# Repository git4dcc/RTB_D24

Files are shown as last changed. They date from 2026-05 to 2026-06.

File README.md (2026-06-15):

# RTB_D24




My Homebrew D24 is a single-sided DIY mobile decoder featuring a NEM-651 connector. While it shares the exact same dimensions as the [D16](https://github.com/git4dcc/RTB_D16), it offers additional AUX channels and supports WS28xx LED connections. It is fully designed for integration into the RTB digital control ecosystem.

<details>
<summary>See also</summary>

- [RTB_D16 - NEM651](/../../../../git4dcc/RTB_D16)
- [RTB_D20 - NEM651](/../../../../git4dcc/RTB_D20)
- [RTB_D21 - Next18](/../../../../git4dcc/RTB_D21)
- [RTB_D22 - Plux16](/../../../../git4dcc/RTB_D22)
- [RTB_D23 - NEM652](/../../../../git4dcc/RTB_D23)

</details>

<details>
<summary>User Guides</summary>

- User Guide - DE
- [User Guide - EN](https://rtb4dcc.de/rtb_decoder_reference_en/)

</details>

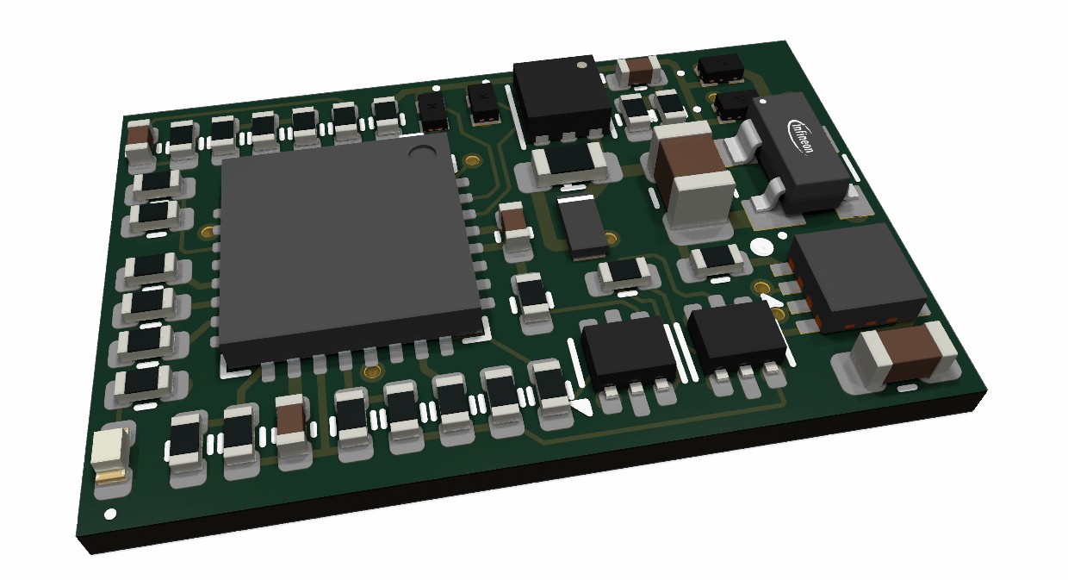
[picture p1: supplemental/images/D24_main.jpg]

<br>

The decoder has the following features,
- **NEM-651** connector
- **DCC**
  - DCC-A automatic logon
  - DCC-R protocol extension
  - Service Mode Programming
- **Railcom**
  - Channel 1/2
  - POM, xPOM
  - DYN: Speed, QoS, Track-voltage, Motor-current, AUX-current, Temp, Distance travelled
- Single sided
- Dimension: 17 x 11 mm
- 7-20V track voltage
- heartbeat LED
- adjustable max motor current (default 300mA)
- adjustable max AUX current (default 500mA)
- over temp protection
- Function output: LV/LR/AUX1/AUX2 (dimmable, 1.4kHz) open drain
- Function output: AUX3/AUX4/AUX5/AUX6/AUX7 logic level (5V)
  - AUX3/AUX4 can be configured to drive WS28xx chips
- optional external buffer capacitor (max. 1500uF)
- <10mA idle power consumption
- Firmware update over main tracks via DCC-R protocol

# Hardware
The current PCB layout uses SMD footprints with 0.5mm pitch and mainly 0402 parts. Reflow soldering is recommended, handsoldering will be difficult.

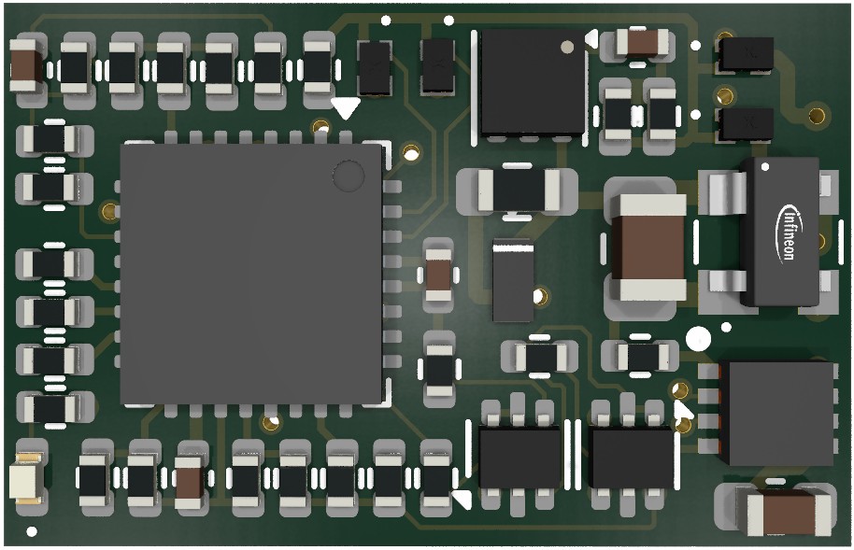
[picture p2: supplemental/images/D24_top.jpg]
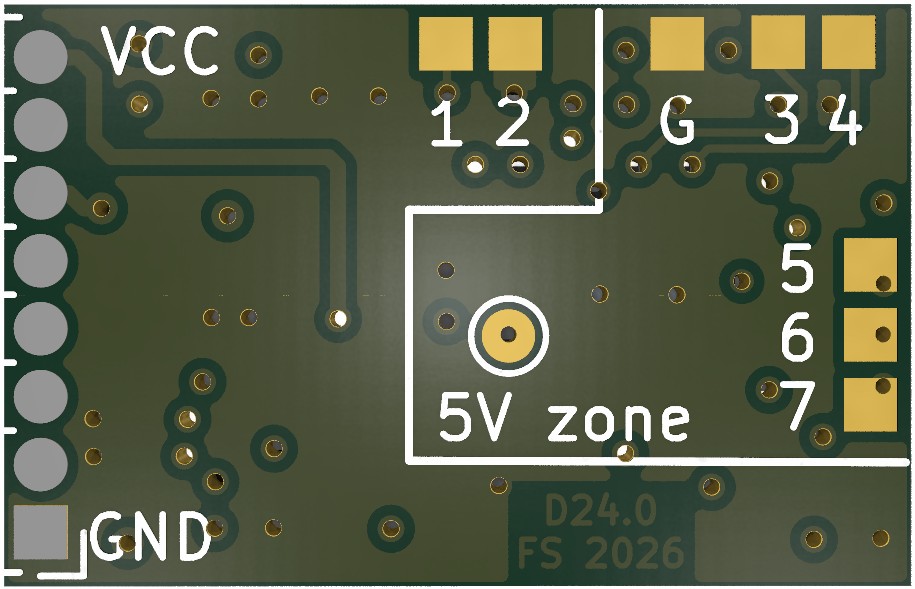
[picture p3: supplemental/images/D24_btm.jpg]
   

**Note:** The '5V zone' silk text can be misleading as the above test point is **not** 5V source but rather the UPDI interface.

## PCB
- 6-layer PCB, FR4, 17 x 11 x 0.8mm (single sided)
- CPU: AVR64DA32
- Motor bridge: DRV8231
- Connector: NEM-651

## Kicad
[Schematic](doc/D24_schematic.pdf) | [Layout](doc/D24_layout.pdf) | [Gerber](gerber)

<details>
<summary>Dependency</summary>
<br>

:yellow_circle: Requires my Kicad project library [RTB_SamacSys](https://github.com/git4dcc/RTB_SamacSys) in the same directory tree.

</details>

## Firmware
Filename structure: { **pcb** }{ **code** }{ **version** }.hex

Example: **D16F0001**.hex

| | Description |
| --- | --- |
| **pcb** | Name of matching hardware (**D24**) |
| **code** | Type of code contained (**R**=rom, **B**=bootloader, **F**=flash, **U**=bld update, **P**=UPDI factory code) |
| **version** | Release version (**####**) |

[Firmware files](firmware)

# Images
| top | bottom |
| --- | --- |
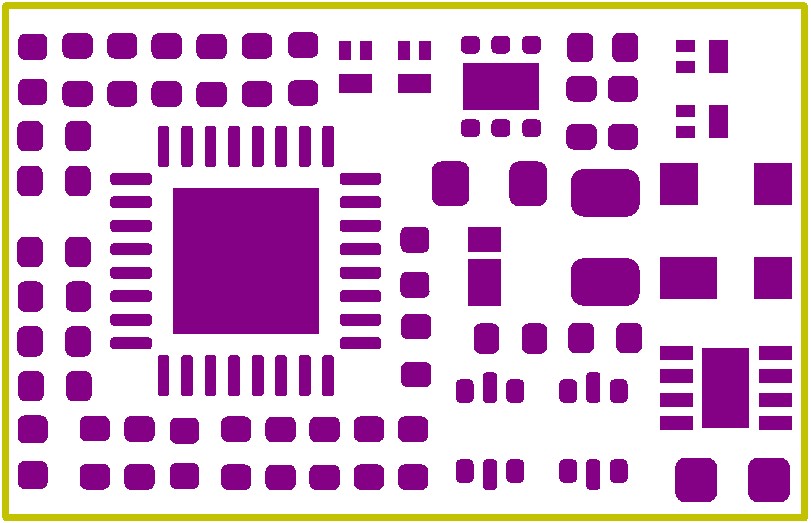
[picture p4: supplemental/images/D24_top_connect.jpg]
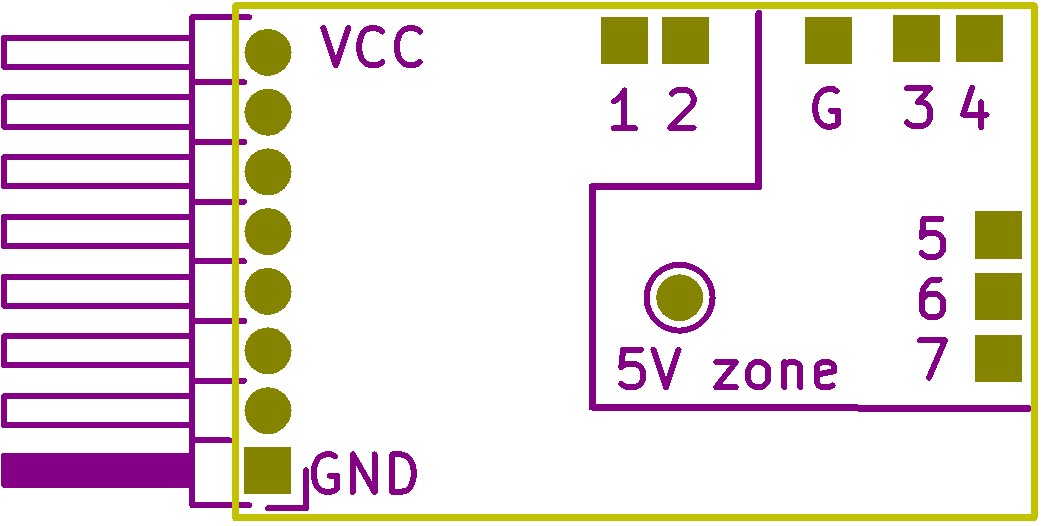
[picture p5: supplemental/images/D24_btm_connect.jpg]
|  |  |

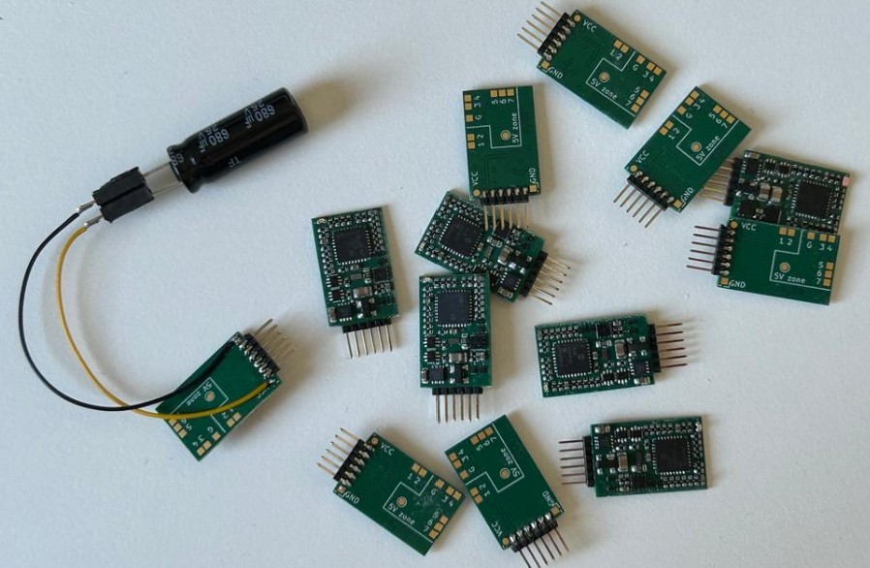
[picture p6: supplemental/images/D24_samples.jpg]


# YouTube
Some YouTubes to see the D24 decoder in action.<br><br>

This project is intended for hobby use only and is distributed in accordance with the Apache License 2.0 agreement.

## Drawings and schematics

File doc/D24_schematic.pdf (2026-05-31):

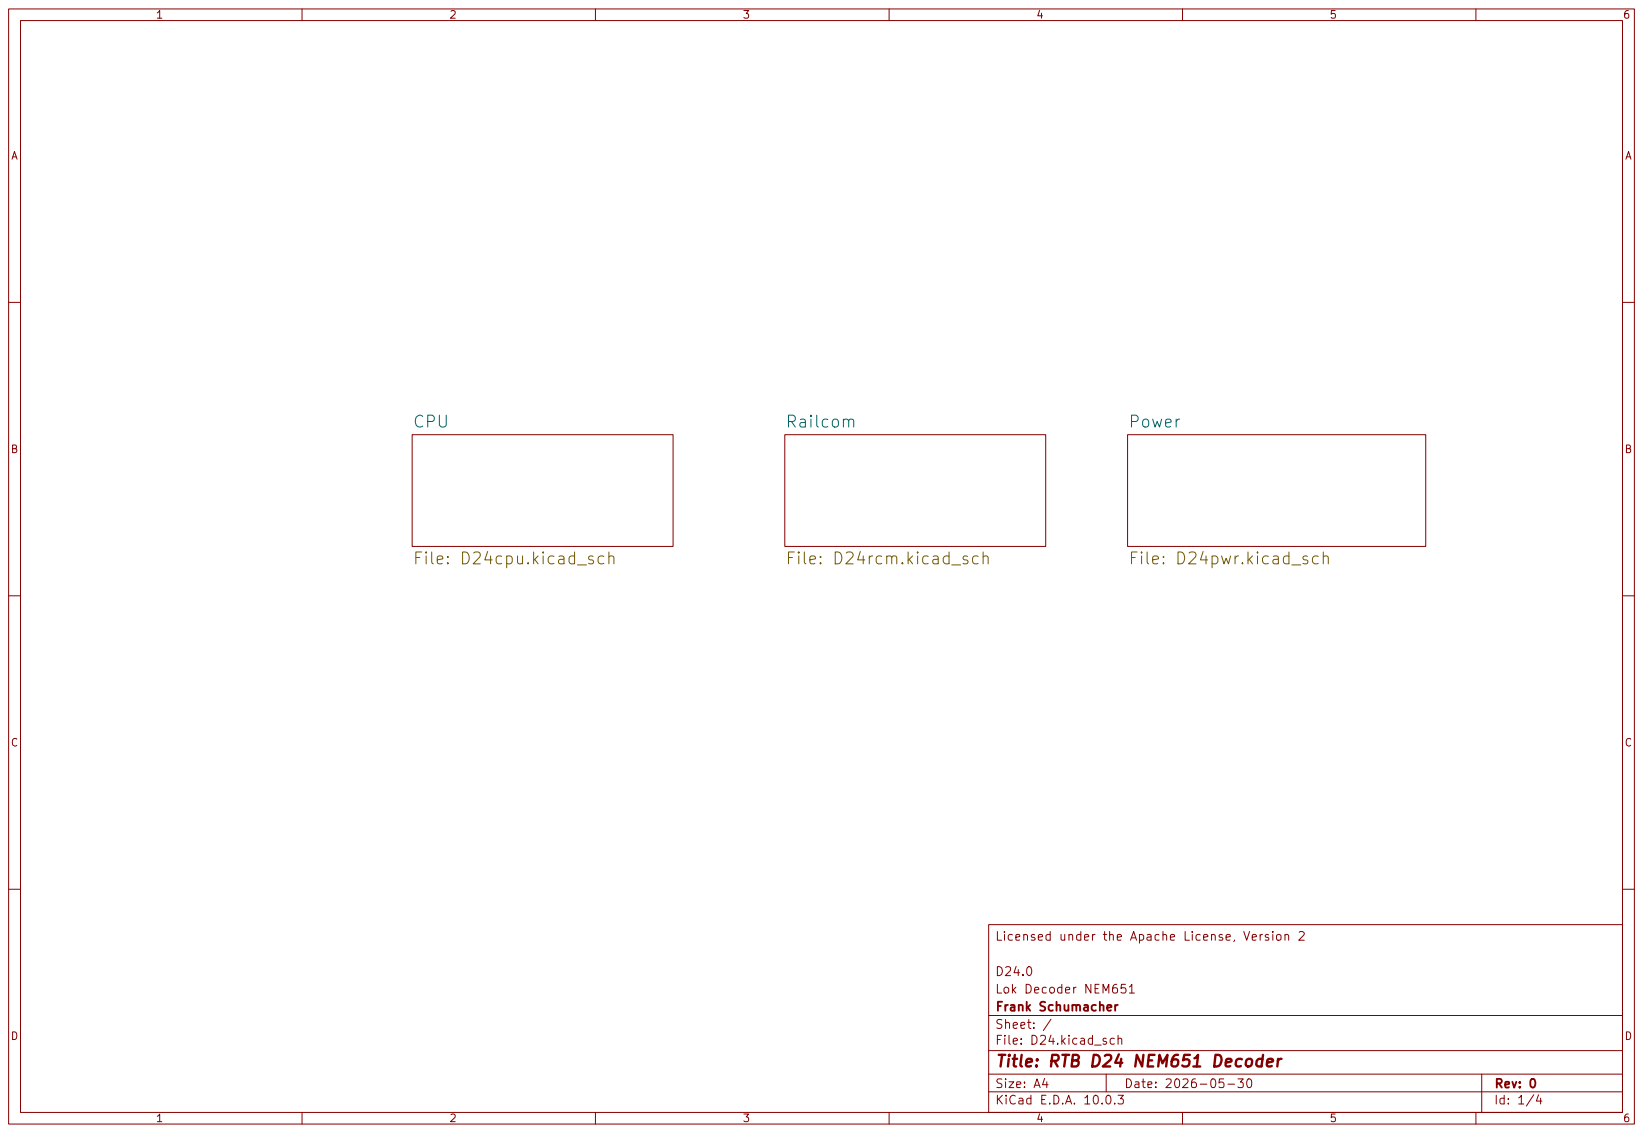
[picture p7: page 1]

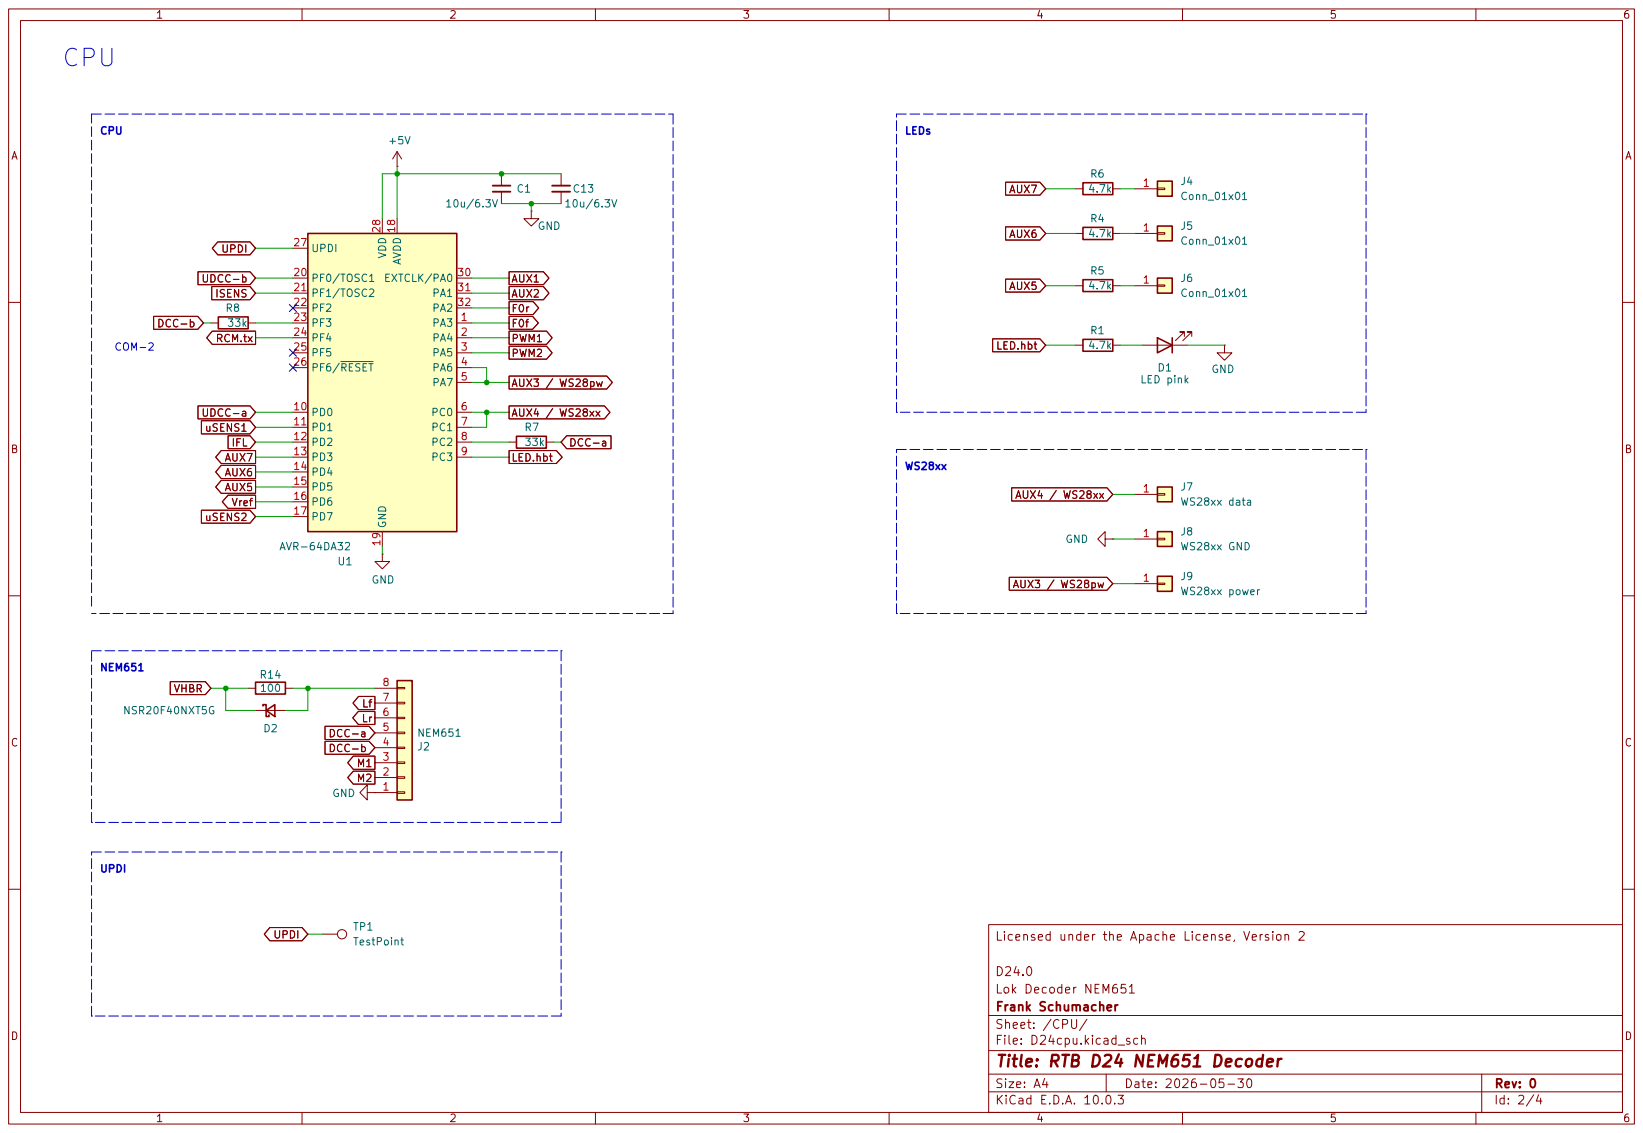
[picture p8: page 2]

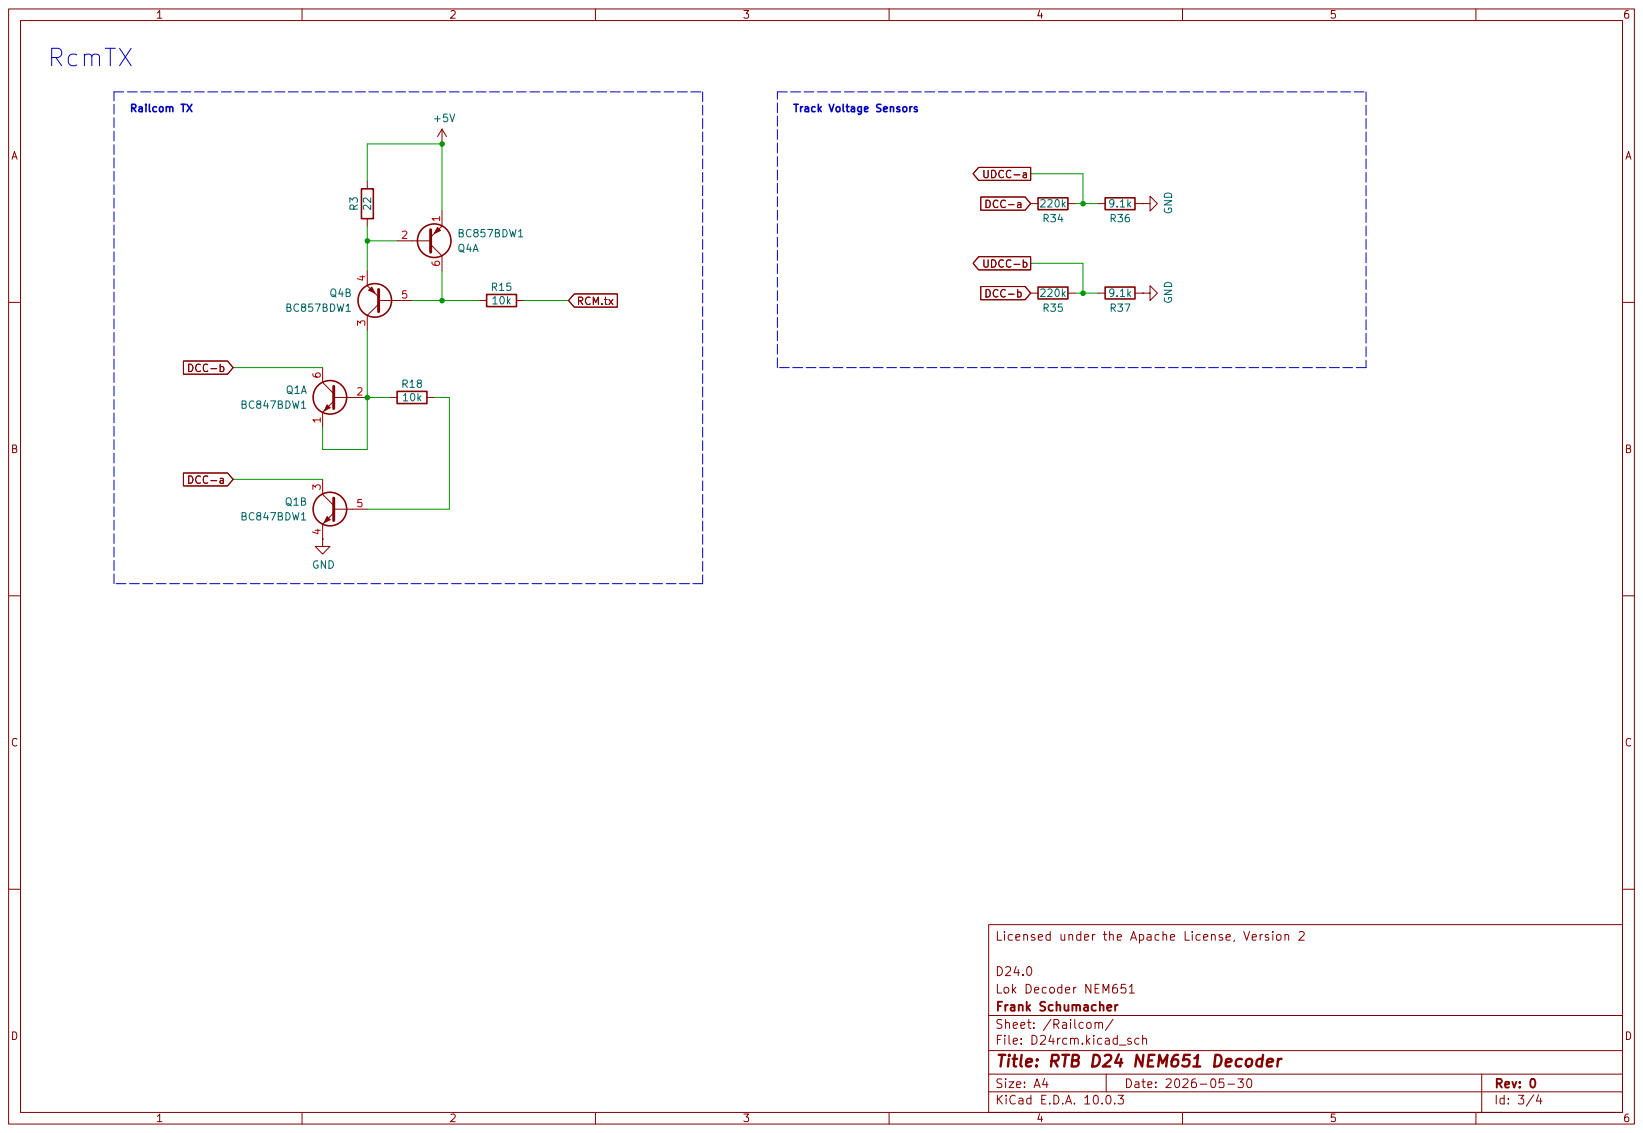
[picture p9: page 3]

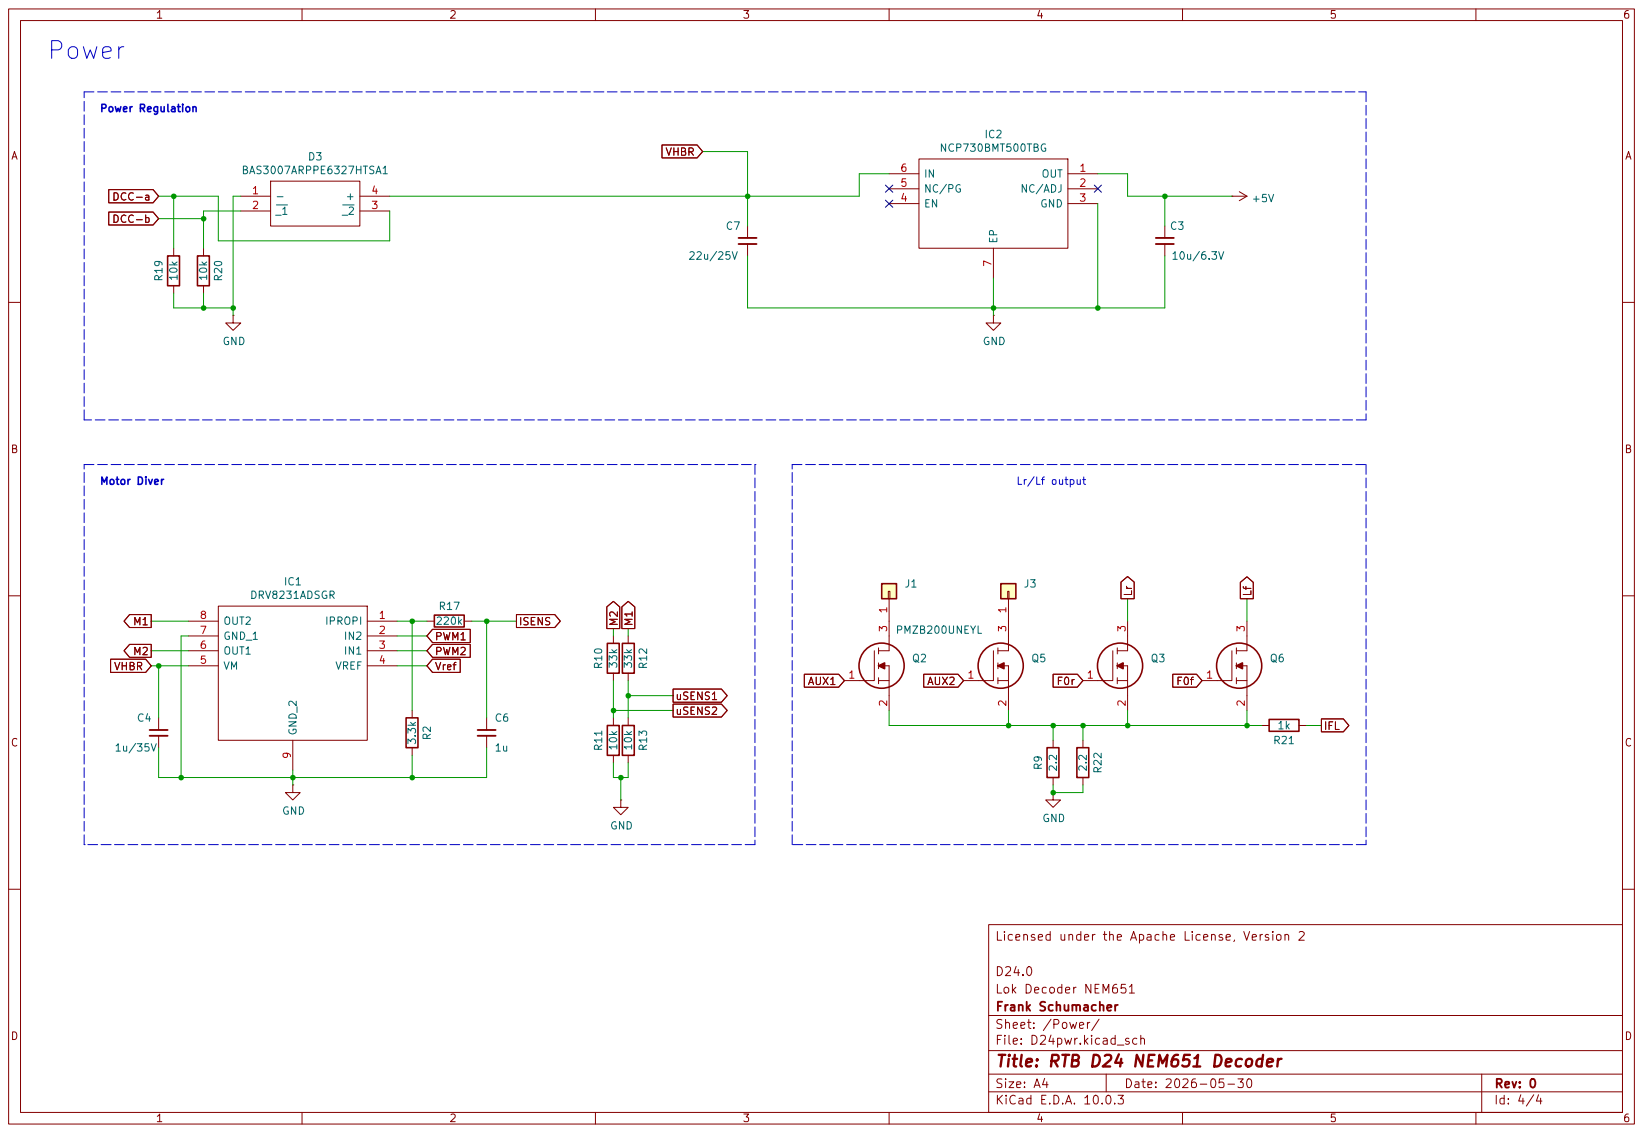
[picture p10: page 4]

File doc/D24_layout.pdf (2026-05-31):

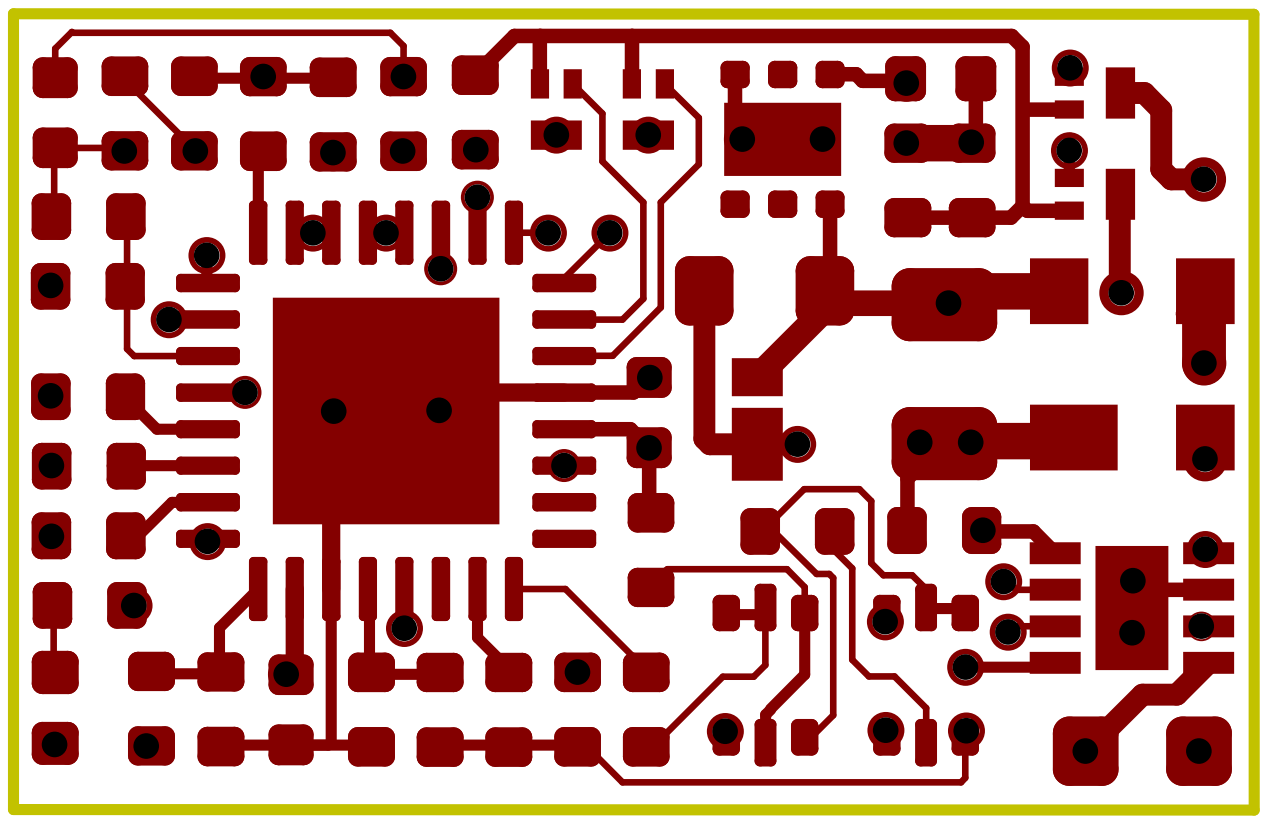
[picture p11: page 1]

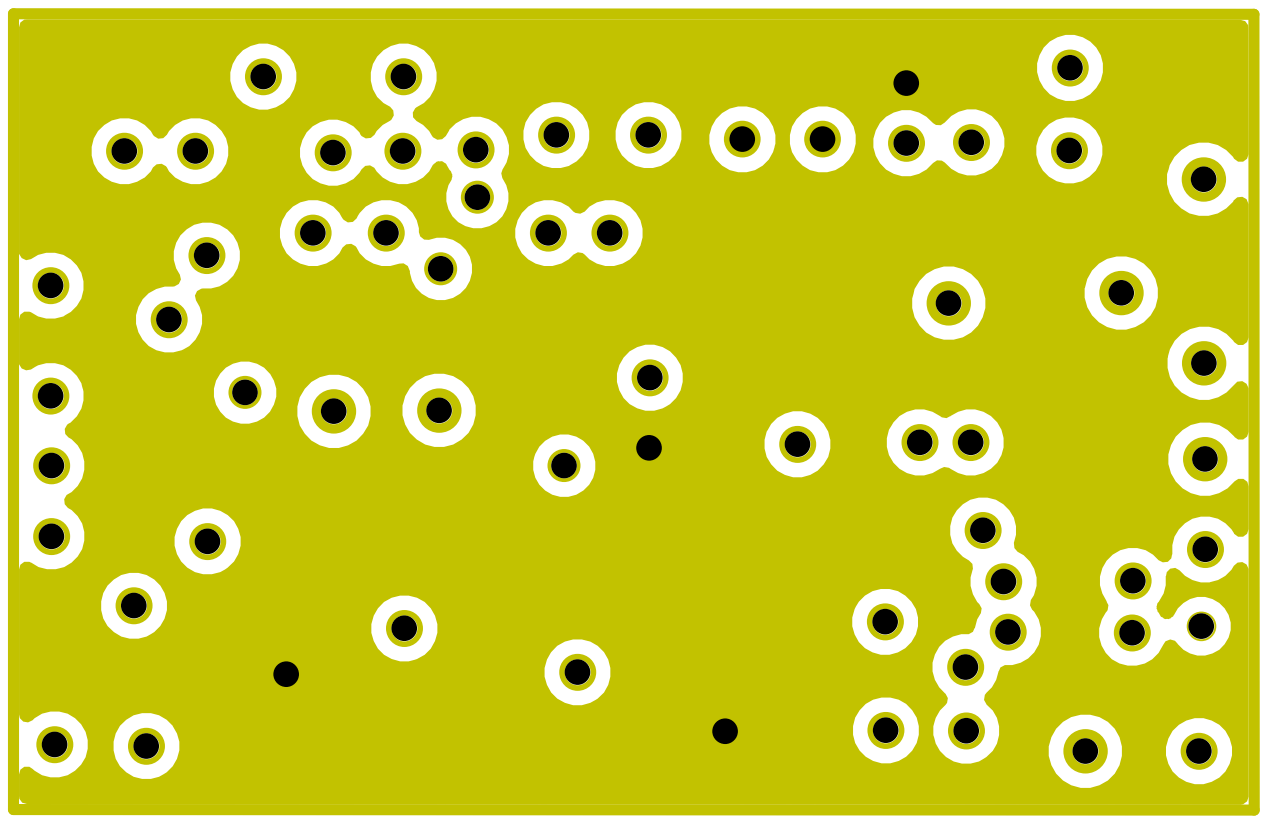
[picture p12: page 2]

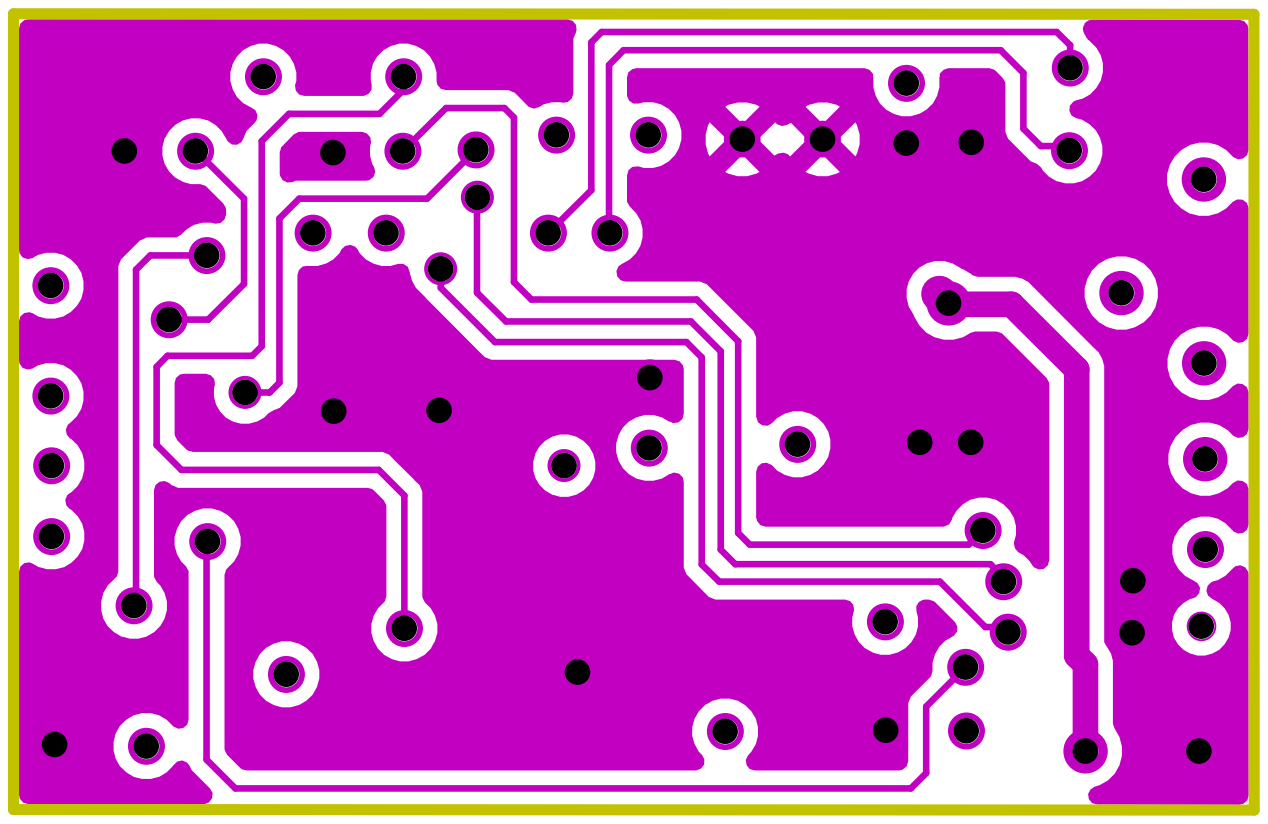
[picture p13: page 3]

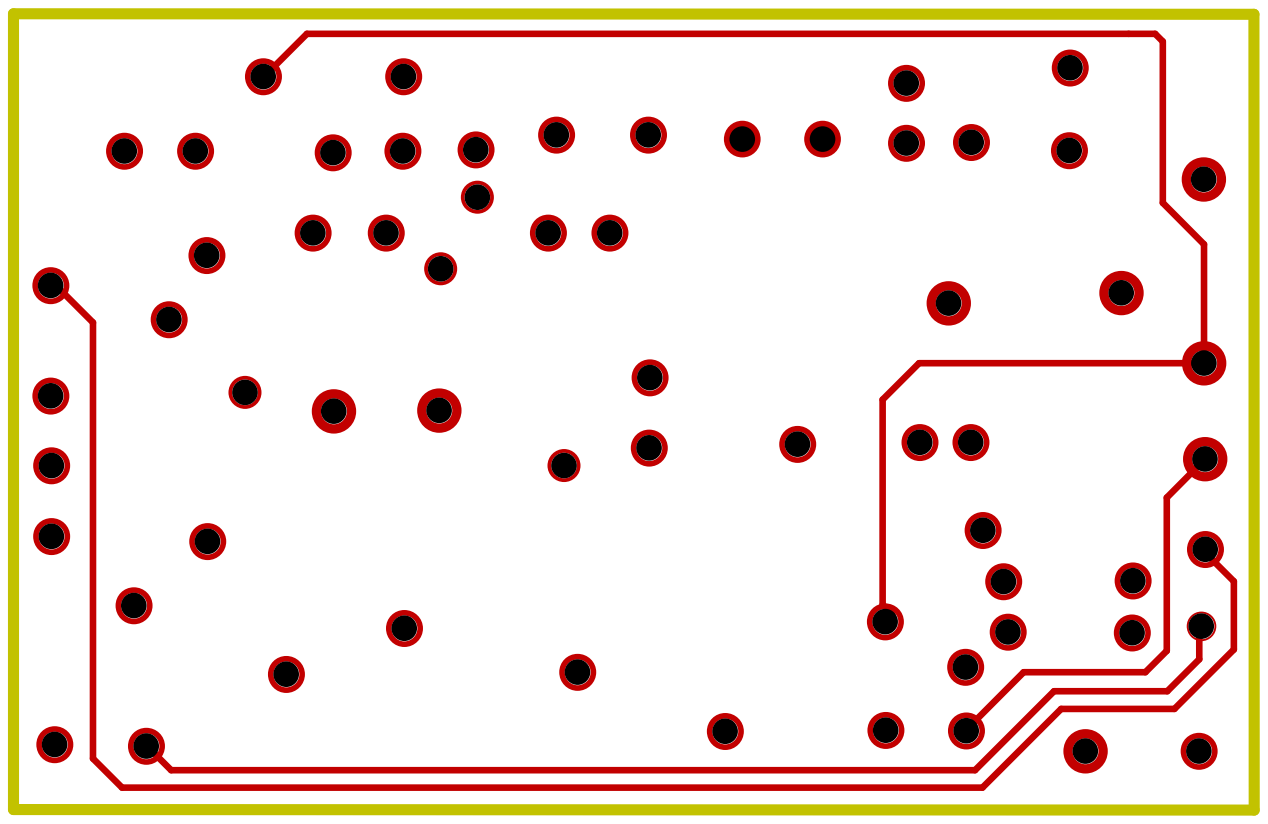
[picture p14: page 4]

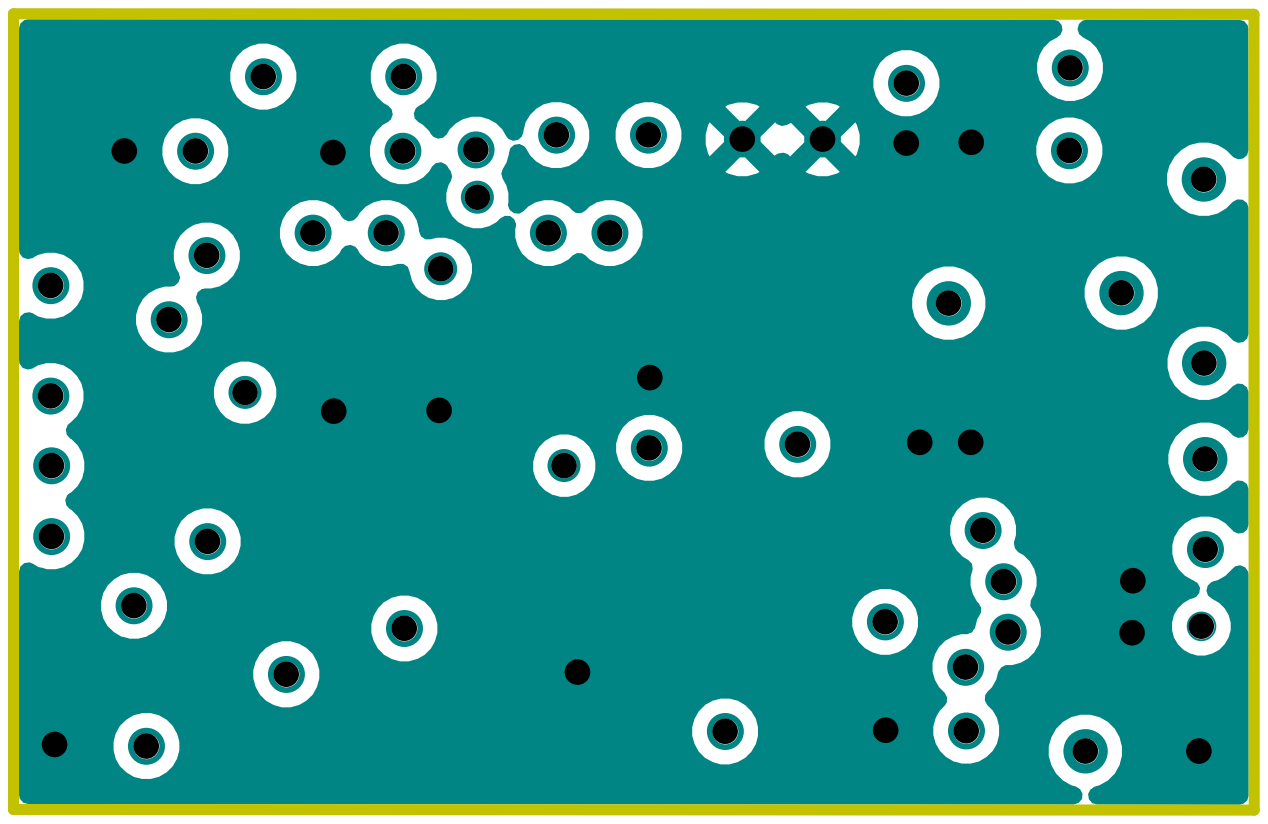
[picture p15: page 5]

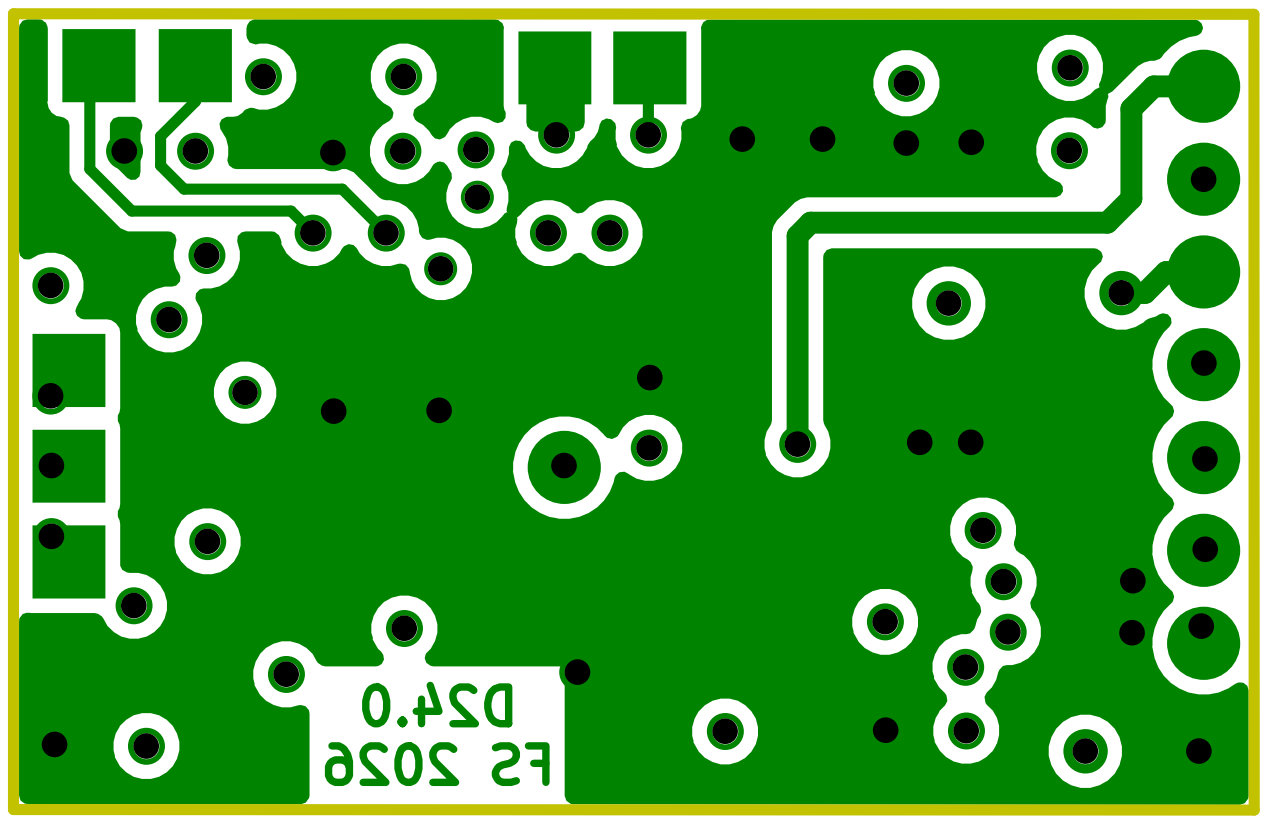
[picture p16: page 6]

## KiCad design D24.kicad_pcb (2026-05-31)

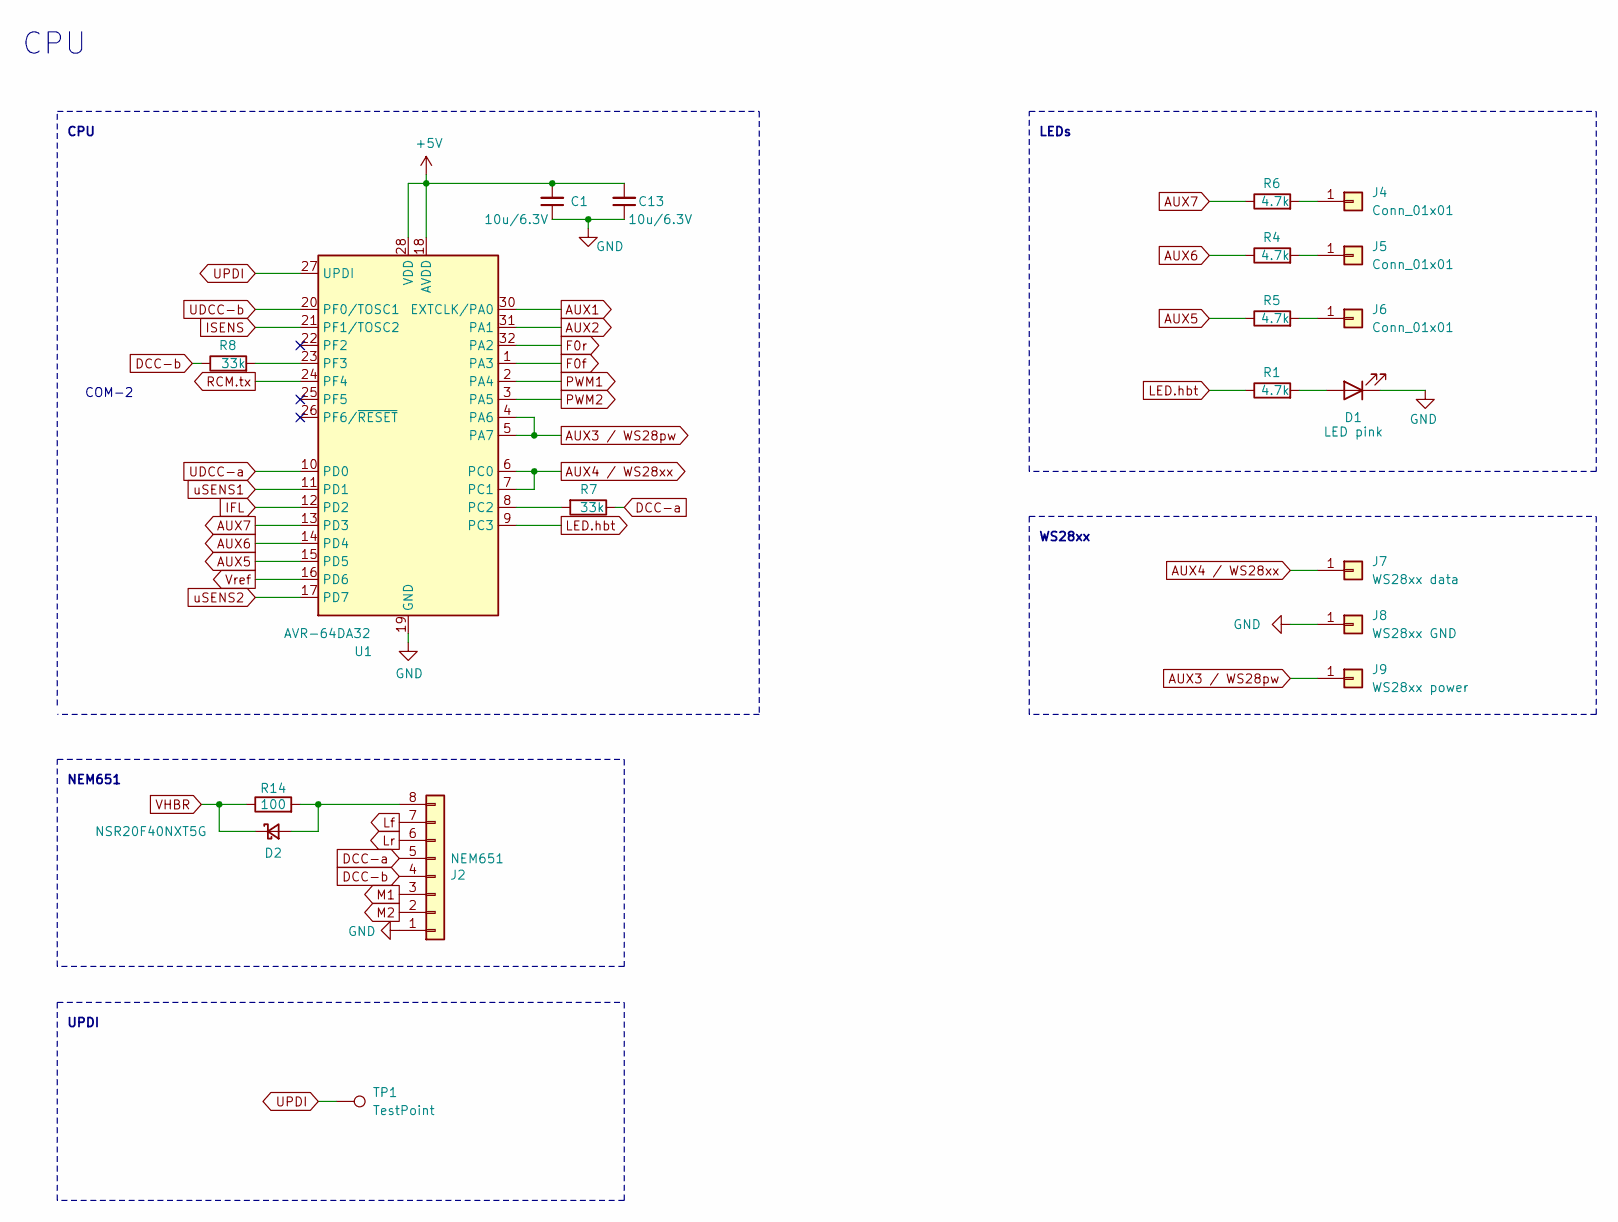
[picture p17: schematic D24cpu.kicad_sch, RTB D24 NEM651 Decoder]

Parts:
C1, C13: 10u/6.3V; C_0402_1005Metric; LCSC Part # C15525
D1: LED pink; LED_0402_1005Metric
D2: NSR20F40NXT5G; LCSC Part # C153761
J2: NEM651; PinHeader_1x08_P1.27mm_Horizontal
J4, J5, J6: Conn_01x01; Solder_Pad_1.0x1.0mm
J7: WS28xx data; Solder_Pad_1.0x1.0mm
J8: WS28xx GND; Solder_Pad_1.0x1.0mm
J9: WS28xx power; Solder_Pad_1.0x1.0mm
R1, R4, R5, R6: 4.7k; R_0402_1005Metric; LCSC Part # C25900
R7, R8: 33k; R_0402_1005Metric; LCSC Part # C25779
R14: 100; R_0603_1608Metric; LCSC Part # C22775
TP1: TestPoint; TestPoint_Pad_D1.0mm
U1: AVR-64DA32; VQFN-32-1EP_5x5mm_P0.5mm_EP3.1x3.1mm; LCSC Part # C3225673

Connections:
+5V: C1.2, C13.2, U1.18 (AVDD), U1.28 (VDD); also elsewhere on the board
AUX1: U1.30 (EXTCLK/PA0); also elsewhere on the board
AUX2: U1.31 (PA1); also elsewhere on the board
AUX3 / WS28pw: J9.1 (Pin_1_1), U1.4 (PA6), U1.5 (PA7)
AUX4 / WS28xx: J7.1 (Pin_1_1), U1.6 (PC0), U1.7 (PC1)
AUX5: R5.1, U1.15 (PD5)
AUX6: R4.1, U1.14 (PD4)
AUX7: R6.1, U1.13 (PD3)
DCC-a: J2.5, R7.1; also elsewhere on the board
DCC-b: J2.4, R8.1; also elsewhere on the board
F0f: U1.1 (PA3); also elsewhere on the board
F0r: U1.32 (PA2); also elsewhere on the board
GND: C1.1, C13.1, D1.1 (K), J2.1, J8.1 (Pin_1_1), U1.19 (GND), U1.29 (GND), U1.33 (GND); also elsewhere on the board
IFL: U1.12 (PD2); also elsewhere on the board
ISENS: U1.21 (PF1/TOSC2); also elsewhere on the board
LED.hbt: R1.1, U1.9 (PC3)
Lf: J2.7; also elsewhere on the board
Lr: J2.6; also elsewhere on the board
M1: J2.3; also elsewhere on the board
M2: J2.2; also elsewhere on the board
unnamed: D1.2 (A), R1.2
unnamed: D2.2 (A), J2.8, R14.2
unnamed: J4.1 (Pin_1_1), R6.2
unnamed: J5.1 (Pin_1_1), R4.2
unnamed: J6.1 (Pin_1_1), R5.2
unnamed: R7.2, U1.8 (PC2)
unnamed: R8.2, U1.23 (PF3)
PWM1: U1.2 (PA4); also elsewhere on the board
PWM2: U1.3 (PA5); also elsewhere on the board
RCM.tx: U1.24 (PF4); also elsewhere on the board
UDCC-a: U1.10 (PD0); also elsewhere on the board
UDCC-b: U1.20 (PF0/TOSC1); also elsewhere on the board
UPDI: TP1.1 (1_1), U1.27 (UPDI)
VHBR: D2.1 (K), R14.1; also elsewhere on the board
Vref: U1.16 (PD6); also elsewhere on the board
uSENS1: U1.11 (PD1); also elsewhere on the board
uSENS2: U1.17 (PD7); also elsewhere on the board

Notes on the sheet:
CPU
WS28xx
NEM651
LEDs
UPDI
COM-2

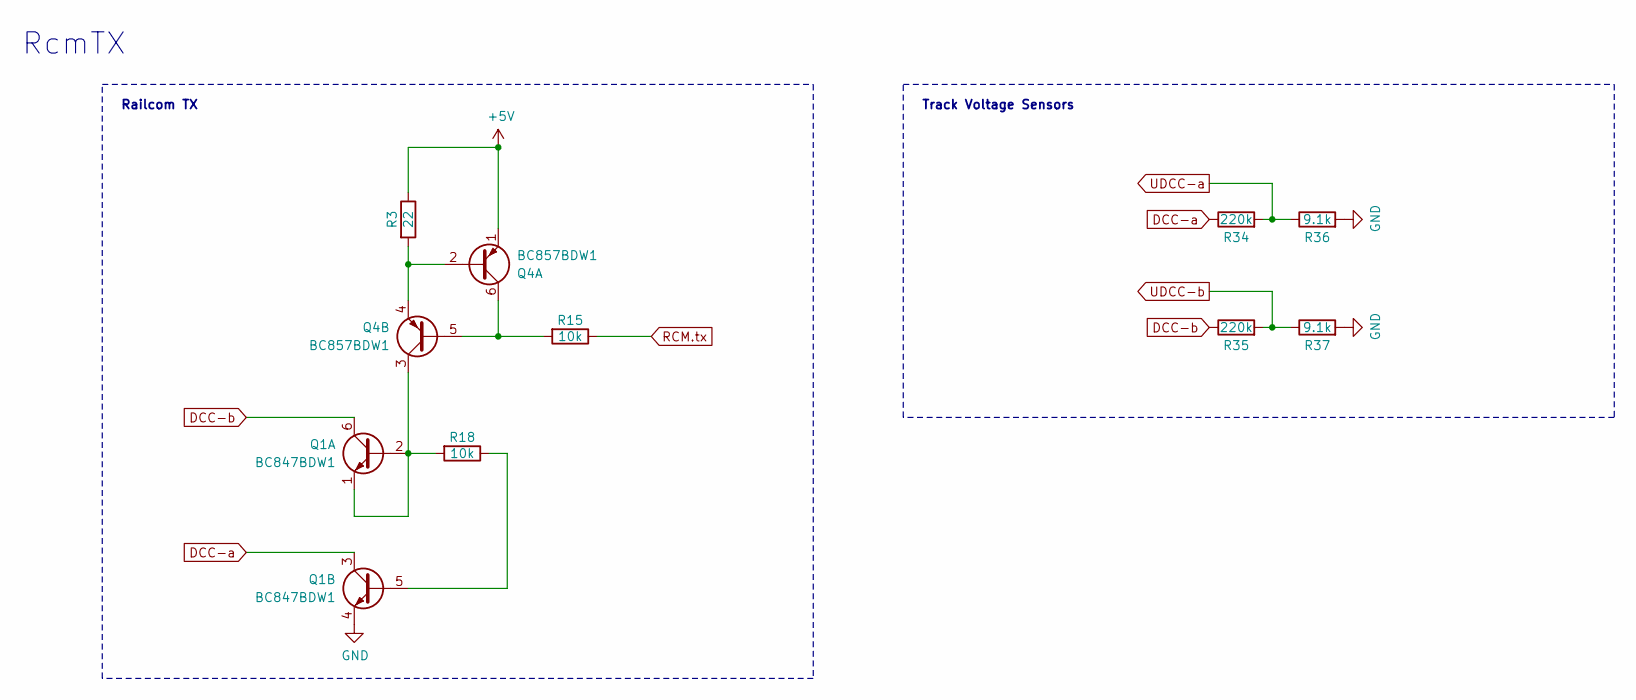
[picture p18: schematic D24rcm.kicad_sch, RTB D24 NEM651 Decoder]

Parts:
Q1: BC847BDW1; SOT-666; LCSC Part # C455062
Q4: BC857BDW1; SOT-666; LCSC Part # C282521
R3: 22; R_0402_1005Metric; LCSC Part # C25092
R15, R18: 10k; R_0402_1005Metric; LCSC Part # C25744
R34, R35: 220k; R_0402_1005Metric; LCSC Part # C25767
R36, R37: 9.1k; R_0402_1005Metric; LCSC Part # C25926

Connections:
+5V: Q4.1 (E1), R3.1; also elsewhere on the board
DCC-a: Q1.3 (C2), R34.1; also elsewhere on the board
DCC-b: Q1.6 (C1), R35.1; also elsewhere on the board
GND: Q1.4 (E2), R36.2, R37.2; also elsewhere on the board
unnamed: Q1.1 (E1), Q1.2 (B1), Q4.3 (C2), R18.2
unnamed: Q1.5 (B2), R18.1
unnamed: Q4.2 (B1), Q4.4 (E2), R3.2
unnamed: Q4.5 (B2), Q4.6 (C1), R15.2
RCM.tx: R15.1; also elsewhere on the board
UDCC-a: R34.2, R36.1; also elsewhere on the board
UDCC-b: R35.2, R37.1; also elsewhere on the board

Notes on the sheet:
Railcom TX
RcmTX
Track Voltage Sensors

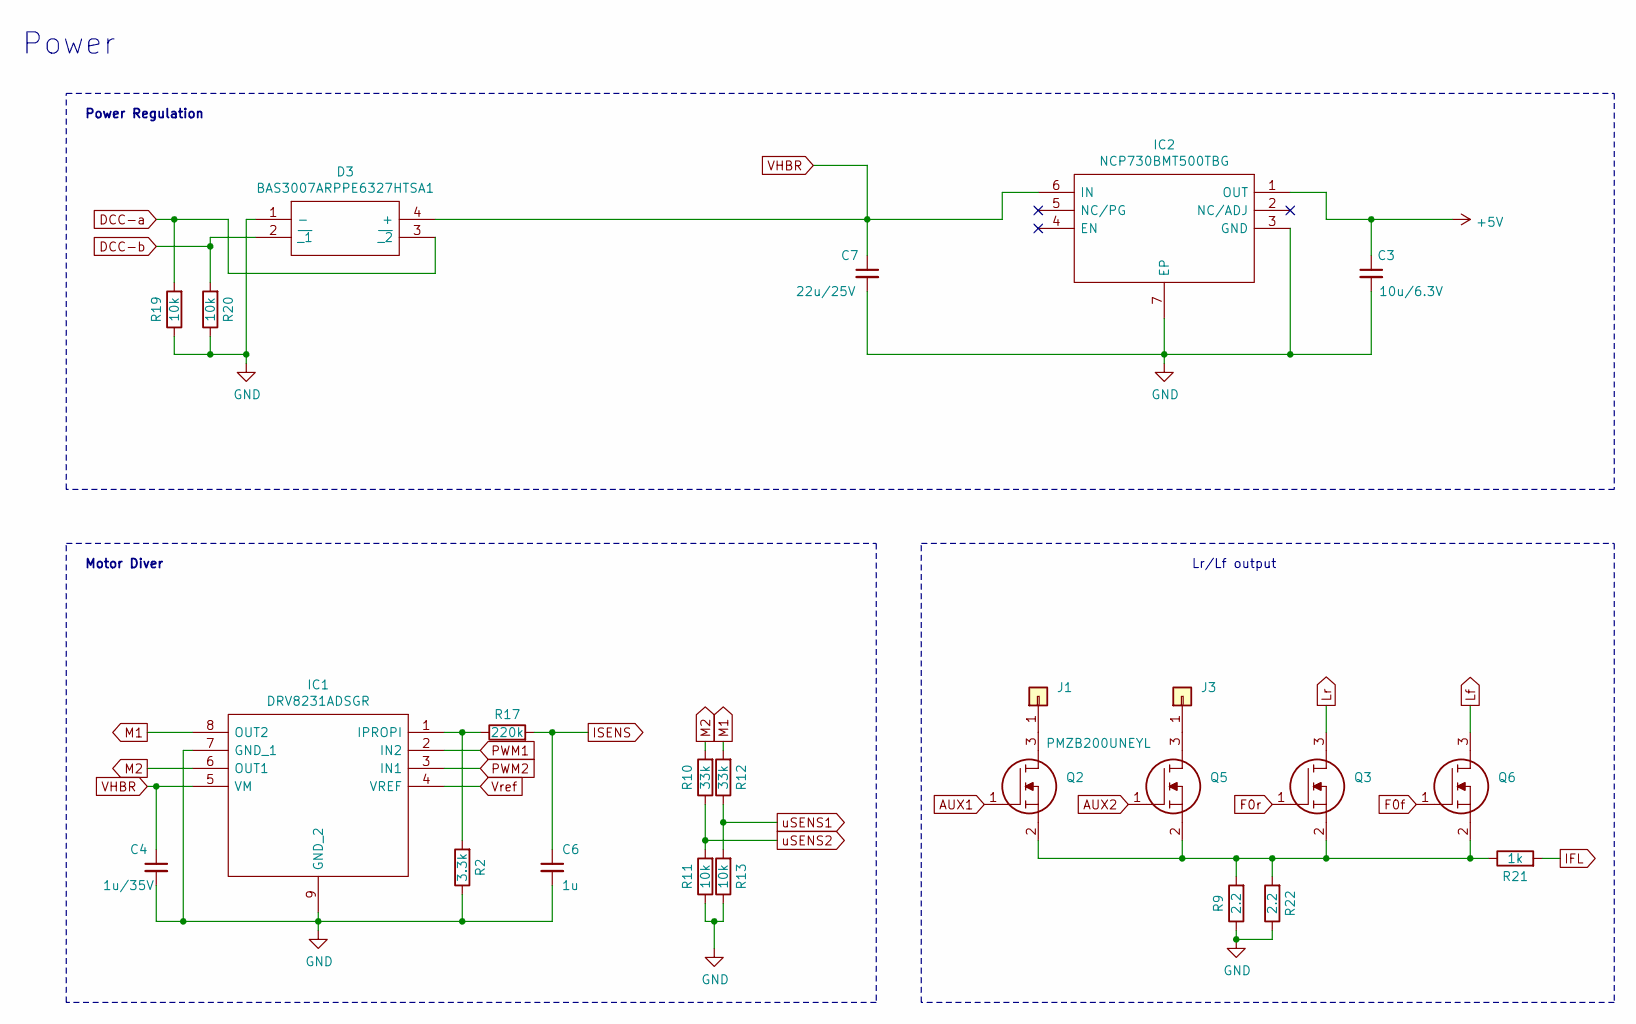
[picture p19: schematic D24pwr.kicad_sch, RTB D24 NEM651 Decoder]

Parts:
C3: 10u/6.3V; C_0402_1005Metric; LCSC Part # C15525
C4: 1u/35V; C_0603_1608Metric; LCSC Part # C15849
C6: 1u; C_0402_1005Metric; LCSC Part # C52923
C7: 22u/25V; C_0805_2012Metric; LCSC Part # C45783
D3: BAS3007ARPPE6327HTSA1; BF998215; LCSC Part # C6430958
IC1: DRV8231ADSGR; SON50P200X200X80-9N; LCSC Part # C5139865
IC2: NCP730BMT500TBG; WSON-6-1EP_2x2mm_P0.65mm_EP1x1.6mm_ThermalVias; LCSC Part # C892822
J1, J3: Conn_01x01; Solder_Pad_1.0x1.0mm
Q2, Q3, Q5, Q6: PMZB200UNEYL; LCSC Part # C547292
R2: 3.3k; R_0402_1005Metric; LCSC Part # C25890
R9, R22: 2.2; R_0402_1005Metric; LCSC Part # C2079158
R10, R12: 33k; R_0402_1005Metric; LCSC Part # C25779
R11, R13, R19, R20: 10k; R_0402_1005Metric; LCSC Part # C25744
R17: 220k; R_0402_1005Metric; LCSC Part # C25767
R21: 1k; R_0402_1005Metric; LCSC Part # C11702

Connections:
+5V: C3.1, IC2.1 (OUT); also elsewhere on the board
AUX1: Q2.1; also elsewhere on the board
AUX2: Q5.1; also elsewhere on the board
DCC-a: D3.3 (~_2), R19.2; also elsewhere on the board
DCC-b: D3.2 (~_1), R20.2; also elsewhere on the board
F0f: Q6.1; also elsewhere on the board
F0r: Q3.1; also elsewhere on the board
GND: C3.2, C4.2, C6.2, C7.2, D3.1 (-), IC1.7 (GND_1), IC1.9 (GND_2), IC2.3 (GND), IC2.7 (EP), R2.1, R9.1, R11.1, R13.1, R19.1, R20.1, R22.1; also elsewhere on the board
IFL: R21.2; also elsewhere on the board
ISENS: C6.1, R17.2; also elsewhere on the board
Lf: Q6.3; also elsewhere on the board
Lr: Q3.3; also elsewhere on the board
M1: IC1.8 (OUT2), R12.2; also elsewhere on the board
M2: IC1.6 (OUT1), R10.2; also elsewhere on the board
unnamed: IC1.1 (IPROPI), R2.2, R17.1
unnamed: J1.1 (Pin_1_1), Q2.3
unnamed: J3.1 (Pin_1_1), Q5.3
unnamed: Q2.2, Q3.2, Q5.2, Q6.2, R9.2, R21.1, R22.2
PWM1: IC1.2 (IN2); also elsewhere on the board
PWM2: IC1.3 (IN1); also elsewhere on the board
VHBR: C4.1, C7.1, D3.4 (+), IC1.5 (VM), IC2.6 (IN); also elsewhere on the board
Vref: IC1.4 (VREF); also elsewhere on the board
uSENS1: R12.1, R13.2; also elsewhere on the board
uSENS2: R10.1, R11.2; also elsewhere on the board

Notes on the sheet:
Lr/Lf output
Motor Diver
Power
Power Regulation

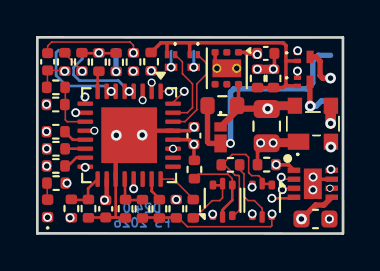
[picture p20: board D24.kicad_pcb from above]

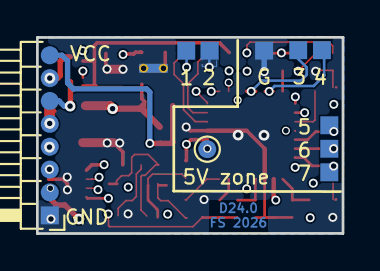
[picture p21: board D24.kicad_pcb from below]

Board: 6 copper layers, 17.0 x 10.9 mm, 53 parts (10 on the bottom side), 45 nets.

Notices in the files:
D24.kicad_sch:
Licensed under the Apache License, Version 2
